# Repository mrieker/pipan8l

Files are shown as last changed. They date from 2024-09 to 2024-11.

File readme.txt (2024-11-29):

- - - - - - - - - - - - -

    Project has been absorbed into pdp8l project
    It is in folder pipan8l within the pdp8l project

- - - - - - - - - - - - -

RasPI-Zero-W uses /dev/i2c-1 to access the I2C bus going to the PCB.
Any RasPI that runs recent RasPI OS and has a 40-pin GPIO connector
should work, but I use a RasPI Zero because it is small, allowing me
to flip the processor over without any issue.

Here is a pic of everything running:

    https://www.outerworldapps.com/pdp8l-with-pipan8l.jpg

The PIPAN8L board is in the lower right corner plugged into the 8/L downside-up.
The PC screen on the left shows the pipan8l program on the lower terminal window,
with the ttpan8l program running on the upper terminal window.

- - - - - - - - - - - - -

The PCB plugs into slot 1 of the PDP-8/L in place of the console.

    RasPI-Zero-W ./pipan8l  ==>  PCB MCP23017s  ==>  PDP-8/L slot 1  ==>  rest of PDP-8/L

The RasPI can be powered from its own USB cable or from the PDP's 5V supply.
To power it from the PDP, install the jumper on the right end of the PCB.
I use the USB power so I can turn the PDP off and the RasPI will not need rebooting.

BE SURE TO USE 1.4mm THICK PCB STOCK.  1.6mm WON'T FIT.  The Digital spec says
board thickness of their modules is 0.056", which is a hair thicker than 1.4mm.
Even at 1.4mm, it takes a little gentle tapping to get it plugged in, so maybe
1.2mm might be better.  But even Digital's modules can be tough to insert.

- - - - - - - - - - - - -

./pipan8l runs the test program.  (You can type ./pip then press tab).
It reads commands from the prompt and can run scripts written in TCL.
The commands echo the switches and lights:

    setsw <switchname> <value>      - sets switch to a value
    getsw <switchname>              - gets value of a switch
    getreg <registername>           - gets value of a register (light bulbs)

And there is a command used to flush series of setsw commands:

    flushit                         - writes out any pending switch changes to MCP23017s
                                    - sets up to read MCP23017s when needed

There are a couple utility commands:

    ctrlcflag                       - sense if control-C has been pressed, optionallly clearing it
                                    - used for test scripts
                                    - otherwise, two control-Cs will abort out of pipan8l

    assemop <mnemonic> <operand>    - assemble the given assembly language instruction
    disasop <opcode>                - disassemble the given opcode to assemly language

And the pipan8lini.tcl script adds some higher-level commands:

    assem <address> <mnemonic> <operand>    - assemble the instruction and deposit in memory
    disas <start> <stop>                    - disassemble the instructions in given memory range
    dumpit                                  - print out all registers and switches
    flicksw <switchname>                    - flick the given switch on then off
    loadbin <filename>                      - load the given bin file into memory
    octal <value>                           - print the given value as 4-digit octal number
    rdmem <address>                         - read memory location
    startat <address>                       - does load address followed by start
    stepit                                  - do a single step then dump switches & lights
    wrmem <address> <value>                 - write the given value to memory

Note:
    The command processor is a TCL interpreter, so all numbers default to decimal.
    Prefix numbers with a 0 if you want to input an octal number.
    Use the octal command to convert number to octal for printing.

So when it's all running, you can do commands like:

    ./pipan8l               ;# start it running
    assem 0200 isz 030      ;# input a simple test program
    assem 0201 jmp 0200
    assem 0202 iac
    assem 0203 jmp 0200
    disas 0200 0203         ;# print it out to verify it
    startat 0200            ;# start it running
    flicksw stop            ;# stop it wherever it is
    setsw step 1            ;# turn on the step mode switch
    stepit                  ;# single cycle and print lights & switches
    stepit
    stepit                  ;# ... 3 times
    setsw step 0            ;# turn single cycle off
    flicksw cont            ;# continue
    dumpit                  ;# see it running
    dumpit
    flicksw stop            ;# stop processor so we can access memory
    octal [rdmem 030]       ;# read the counter and print in octal
    startat 0200            ;# restart program

Logged into RasPI:

$ sudo apt install tcl-dev
$ make
    ...
$ ./pipan8l

          ST=F  AC=0.7777 MA=0.7240 MB=7777 IR=7  OPR  SR=0000 DFLD IFLD MPRT STEP

TCL scripting, do 'help' for pipan8l-specific commands
  do 'exit' to exit pipan8l
pipan8l> assem 0200 isz 030
pipan8l> assem 0201 jmp 0200
pipan8l> assem 0202 iac
pipan8l> assem 0203 jmp 0200
pipan8l> disas 0200 0203
0200  2030  ISZ   0030
0201  5200  JMP   0200
0202  7001  IAC
0203  5200  JMP   0200
pipan8l> startat 0200
pipan8l> flicksw stop
pipan8l> setsw step 1
pipan8l> stepit
          ST=E  AC=0.0000 MA=0.0030 MB=0000 IR=2  ISZ  SR=0203 DFLD IFLD MPRT STEP
pipan8l> stepit
          ST=F  AC=0.0000 MA=0.5027 MB=5747 IR=2  ISZ  SR=0203 DFLD IFLD MPRT STEP
pipan8l> stepit
          ST=F  AC=0.0000 MA=0.0200 MB=2577 IR=5  JMP  SR=0203 DFLD IFLD MPRT STEP
pipan8l> setsw step 0
pipan8l> flicksw cont
pipan8l> dumpit
  RUN     ST=F  AC=0.0003 MA=0.4230 MB=5755 IR=3  DCA  SR=0203 DFLD IFLD MPRT
pipan8l> dumpit
  RUN     ST=E  AC=0.0005 MA=0.0100 MB=4177 IR=2  ISZ  SR=0203 DFLD IFLD MPRT
pipan8l> dumpit
  RUN     ST=F  AC=0.0006 MA=0.0233 MB=0560 IR=3  DCA  SR=0203 DFLD IFLD MPRT
pipan8l> flicksw stop
pipan8l> octal [rdmem 030]
4521
pipan8l> startat 0200
pipan8l>

- - - - - - - - - - - - -

It is somewhat tedious to keep entering dumpit commands to see what the panel is doing.
So there is a program called ttpan8l that will continuously dump the panel contents in
similar format to the actual PDP-8/L panel:

  PDP-8/L       -   - - -   - * -   - * *   - * -  0.0232  MA   IR [ - * *  DCA ]           1804 fps

                    * - -   * - *   * - *   - * -    4552  MB   ST [ f E d wc ca b ]

                -   - - -   - * *   - * -   - * -  0.0322  AC   ion per prt RUN

  MPRT  DFLD IFLD   - - -   - * -   - - -   - * *    0203  SR   ldad  start cont stop step exam  dep

Capital letters indicate the light is ON.
Small letters incdicate it is off.
Also, the ON lights are highlighted in green.

Leave pipan8l running in one terminal window of the RasPI.

Then, you can either run ttpan8l from another terminal window of the RasPI:

    ./ttpan8l

Or you can run it from a terminal window of a PC:

    ./ttpan8l <ip-address-of-raspi>

It does UDP to the pipan8l program to read the panel state as fast as it can.

- - - - - - - - - - - - -

There is a simple memory test script, testmem.tcl.
To use it:

    ./pipan8l testmem.tcl

    testzeroes 0 077            ;# test writing zeroes to memory 0000..0077
                                ;# writes then verifies

    testrands 0100 0177         ;# writes random numbers to 0100..0177 then verifies

    looptest testrands          ;# writes random numbers to 0000..0037 then verifies
                                ;#  then does 0040..0077 and verifies
                                ;#  then does 0100..0137 and verifies
                                ;#      ...
                                ;#  all the way through to 7740..7777
                                ;#  then repeats forever

Note:
    These tests run by simulating deposit and examine console operations so do not require that
    the processor be able to run a program.  It is just like someone manually doing load address,
    deposit and examines, flicking switches and reading lights, but it's all automated.

    The PDP-8/L circuitry limits the rate of panel operations (load address, examine, deposit, etc)
    to about 10 per second (for switch debouncing).  So these tests run S-L-O-W-L-Y.  But it beats
    doing it by hand!

$ ./pipan8l testmem.tcl

          ST=E  AC=0.1314 MA=0.0030 MB=0000 IR=2  ISZ  SR=0030 DFLD IFLD MPRT

  looptest - wrap one of the below test to run continuously
  testzeroes [beg [end]] - writes zeroes to all memory then verifies
  testones [beg [end]] - writes ones to all memory then verifies
  testrands [beg [end]] - writes randoms to all memory then verifies

TCL scripting, do 'help' for pipan8l-specific commands
  do 'exit' to exit pipan8l
pipan8l> looptest testrands

PASS 1

write randoms 0000..0037...
 0000
verify randoms...
 0000: 5476       0453       6021       3630       3042       7403       7603       7006      
 0010: 6343       2240       0554       5052       6070       4357       0443       1714      
 0020: 4525       2447       5673       5475       5153       7647       4334       4777      
 0030: 3427       5527       0065       0560       4074       4412       6431       2176      
write randoms 0040..0077...

verify randoms...
 0040: 6633       5621       7064       6502       4116       5460       6045       5404      
 0050: 2353       3512       1610       4655       7162       1455       0204       2604      
 0060: 6124       4103       6756       5633       3630       1045       0376       2535      
 0070: 6567       0310       5311       3551       4376       6131       6133       2620      
write randoms 0100..0137...
 0100
verify randoms...
 0100: 7356       6277       7265       5057       4612       2453       7610       5016      
 0110: 2501       1631       1034       3662       6530       6421       7232       5563      
 0120: 6133       7601       2607       0475       5310       1223       0230       0133      
 0130: 3302       1425       2162       0576       5154       3105       0162       0132      
write randoms 0140..0177...

verify randoms...
 0140: 6554       3664       2233       0117       0740       4636       3725       7377      
 0150: 7375       3102       3445       3022       6025       4306       6576       4673      
 0160: 2404       7613       1611       3307       2613       1267       3407       2102      
 0170: 1546       5553       2043       5753       4444       0007       6152       2125      
write randoms 0200..0237...

Here is example output with a broken memory:

verify randoms...
 0000: 7732       5502       0231!=1771 7464       3560       1064       5730       2377      
 0010: 7375       4246       1242!=1666 3224       4575       1537       3413       1176      
 0020: 7073       3573       0006!=1027 1612       0216       0744       2370       3205!=3204
 0030: 1007       5501       2044!=7144 7655       5171       6066       3023       2437      
 0040: 6355       4405       2353!=2757 6220       0563       6101       7601       6625      
 0050: 7147       3323       2014!=3614 3347       4360       5405       2725       0326      
 0060: 6773       6361!=2360 2757!=0714 7663       6745       6574       4167       0760      
 0070: 3444       2046       1104!=3104 2461       1606       7437       2360       4746      
 0100: 2425       0710       4006!=7327 0163       6610       7104       2370       3022      
 0110: 0246       1307       2014!=3515 3146       7261       0212       1023       5405      
 0120: 1526       1515       4102!=4123 3770       1405       0464       3416       2317!=2316
 0130: 0432       2531       5246!=5756 0713       4227       5537       0561       7164      
 0140: 0735       7736       0110!=3314 0066       5141       0377       6707       4753      
 0150: 6760       6203       1025!=3025 3551       5451       5634       7334       4476      
 0160: 7416       6567!=4567 7757!=7756 1442       7417       2605       1020       6734      
 0170: 3106       1414       0137!=0537 5142       2133       2045       3725       4332      
 0200: 3162       1570       0000!=0212 5752       3554       1153       4414       1204      
 0210: 3345       2605       0000!=3200 0417       5403       0227       1676       3160      
 0220: 5074       2470       0006!=6617 2367       3341       3555       5204       2455      
 0230: 1016       5226       2401!=2621 6533       3131       7554       1325       1741      
 0240: 6507       0162       0001!=2373 5762       1014       6243       7537       1353      
 0250: 7167       2177       0020!=0023 4406       7050       0275       0236       5150      
 0260: 7351       5001!=5000 4651!=4251 1177       1361       5122       6003       2647      
                                    ^ shorted diode                                        ^ bad inhibit driver resistor
                         ^ shorted diode

- - - - - - - - - - - - -

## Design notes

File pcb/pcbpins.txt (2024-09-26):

AA1 SW MPRT     A28
AB1 SW DFLD     A27
AC1 SW IFLD     B28
AD1 SW SR04     A26
AD2 SW SR03         A01
AE1 LT LINK     A25
AE2 SW SR02         A02
AF1 LT EMA      A24
AF2 SW SR01         A03
AH1 LT MB01     A23
AH2 SW SR00         A08
AJ1 LT MA01     A22
AJ2 LT AC00         A04
AK1 LT AC03     A21
AK2 LT MB00         A05
AL1 LT AC02     B27
AL2 LT AC01         A06
AM2 LT MA00     A07
AN2 LT MB02         B01
AP2 LT MA02         B02
AR2 LT MB03         B03
AS2 LT MA03     B26
AT2 LT MB04         B04
AU2 LT MA04     B25

BD2 LT AC04     B24
BE2 LT AC05         B05
BF2 LT MB05     B23
BH2 LT MA05         B06
BJ2 LT AC06     B22
BK2 LT AC07         B07
BL2 LT MB06     B21
BM2 LT MA06         C01
BP2 LT MA07         C02
BR2 LT MB07         C03
BS2 LT MB08     C27
BT2 LT MA08     C26
BU2 LT AC08     C25
BV2 LT AC09     C24

CD1 LT MB09     C22
CD2             C23
CE1 LT MA09     C21
CE2 SW SR09     C28
CF1 LT AC11     D27
CF2 SW SR10         B08
CH1 LT AC10     D26
CH2 SW SR08         C04
CJ1 LT MA10     D25
CJ2 SW SR07         C05
CK1 LT MB10     D24
CK2 SW SR06         C06
CL2 SW SR05         C08
CM1             D23
CM2 LT MB11         C07
CN2 LT MA11         D01
CP2 LT FET          D02
CR2 LT IR00         D03
CS2 LT ION          D04
CT2 LT PARE         D05
CU1             D22
CU2 LT EXE          D06
CV2 LT IR01         D21
CV2 LT IR01         D07

DB1             C21
DD2 LT IR02         E01
DE2 LT DEF      E27
DF2 LT PRTE         E02
DH1             E26
DH2 LT RUN          E03
DJ1             E25
DJ2 LT WCT          E04
DK2 LT CAD      E24
DL2 LT BRK          E05
DM2 SW SR11         E06
DN1 SW BNCY     E23
DN2 SW STOP     E22
DP2 SW CONT         E07
DR2 SW STRT     E21
DS2 SW LDAD         E08
DT2 SW STEP     E28
DU2 SW EXAM         D08
DV2 SW DEPO     D28

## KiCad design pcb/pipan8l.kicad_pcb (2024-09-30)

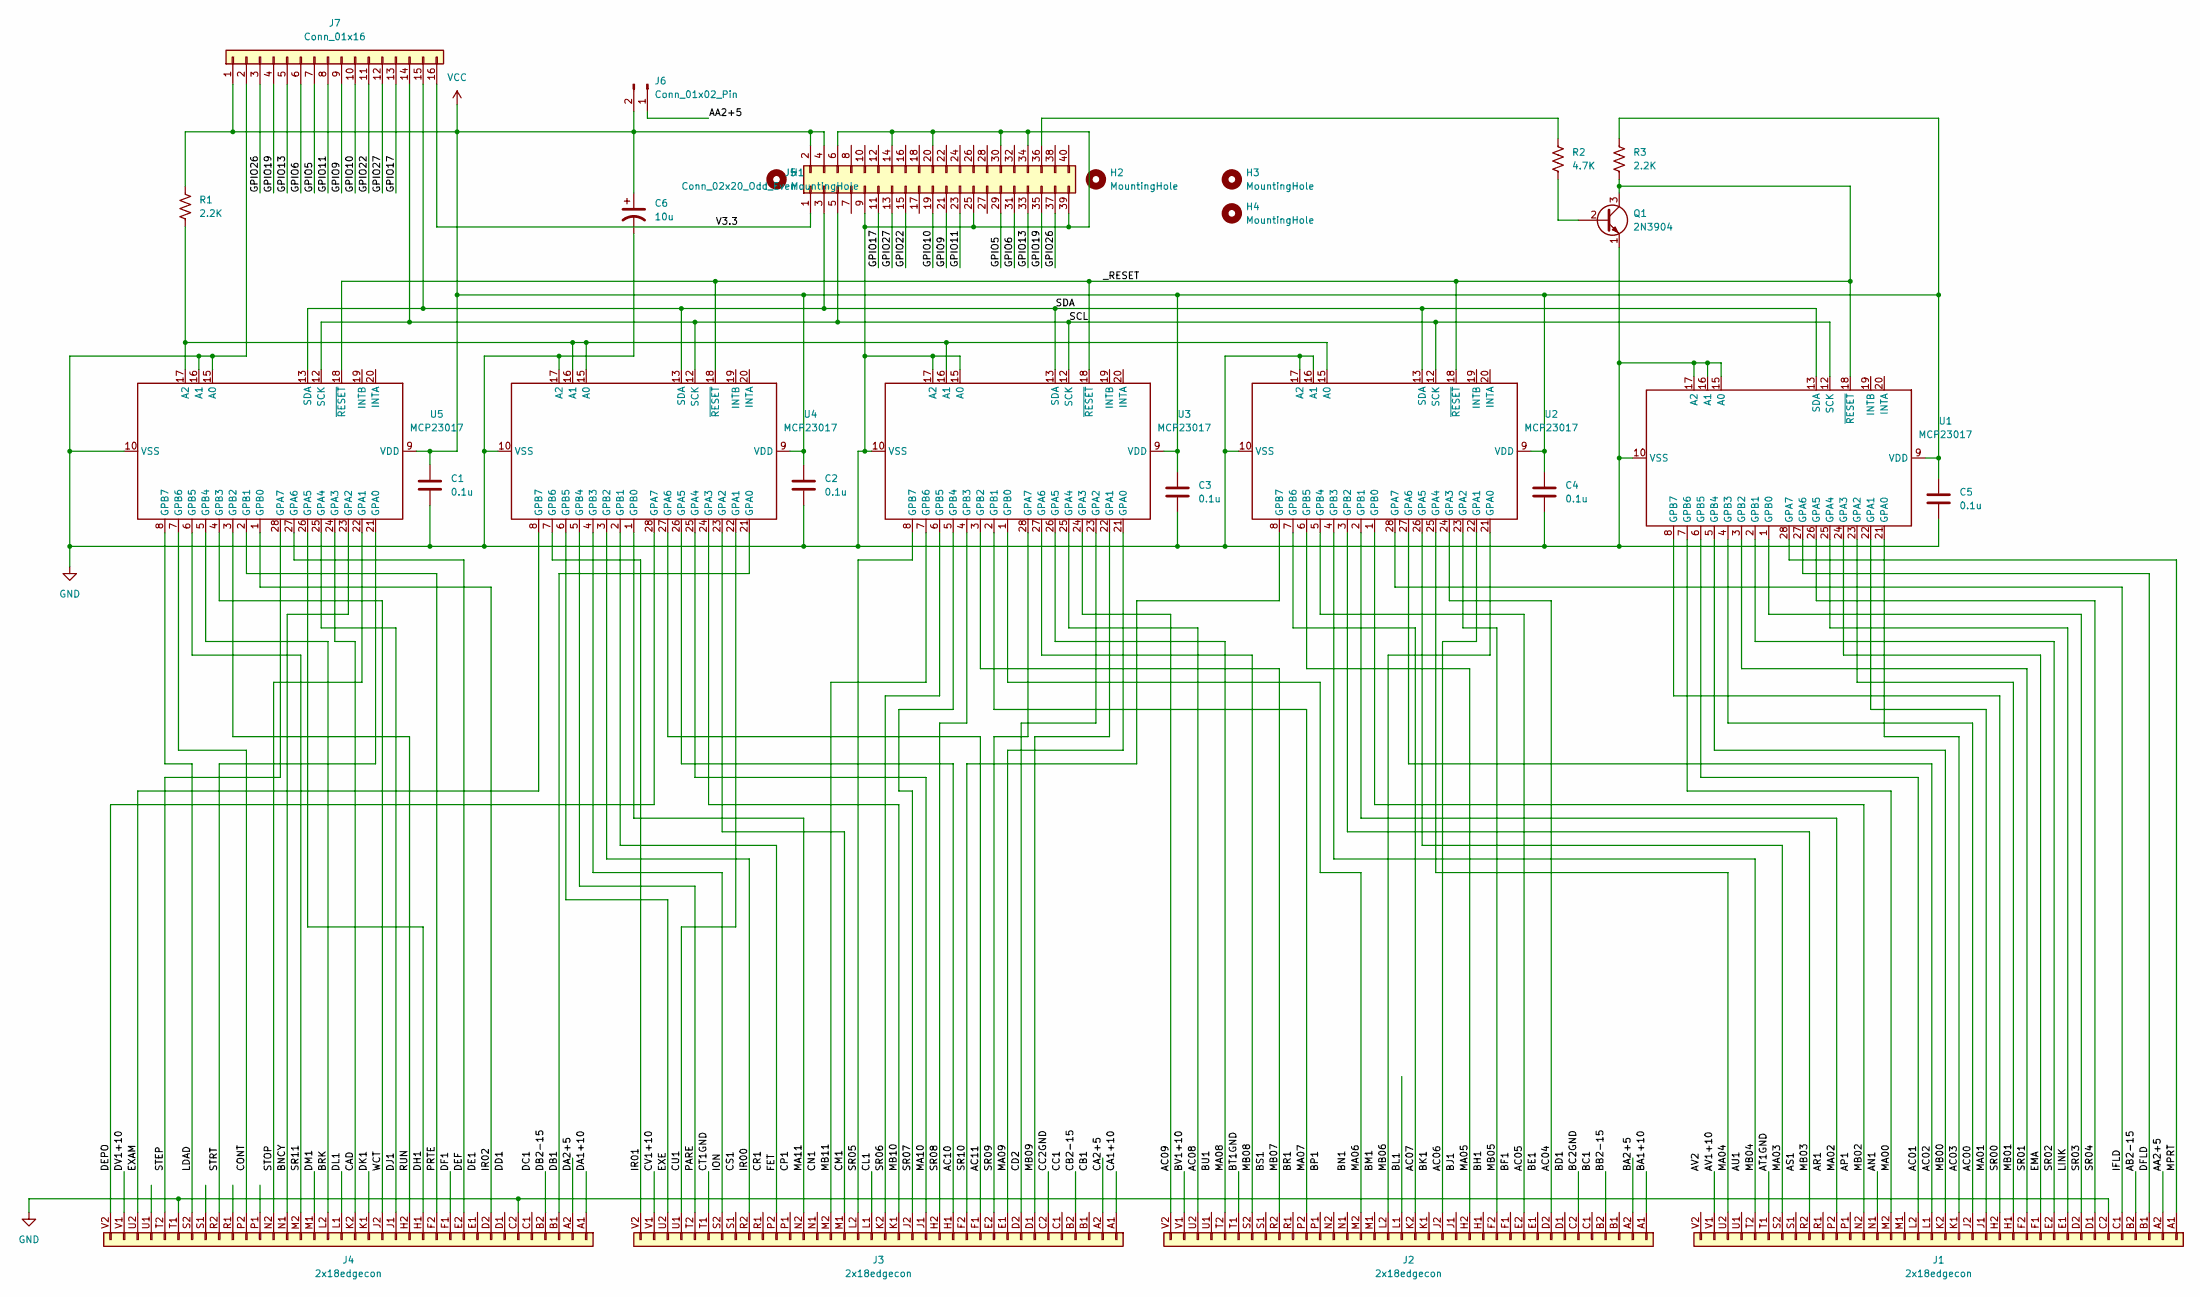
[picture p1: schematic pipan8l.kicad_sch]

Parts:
C1, C2, C3, C4, C5: 0.1u; C_Axial_L3.8mm_D2.6mm_P7.50mm_Horizontal
C6: 10u; CP_Axial_L11.0mm_D5.0mm_P18.00mm_Horizontal
H1, H2: MountingHole; MountingHole_3mm
H3, H4: MountingHole; MountingHole_8.4mm_M8
J1, J2, J3, J4: 2x18edgecon; 2x18-edge
J5: Conn_02x20_Odd_Even; PinHeader_2x20_P2.54mm_Vertical
J6: Conn_01x02_Pin; PinHeader_1x02_P2.54mm_Vertical
J7: Conn_01x16; PinHeader_1x16_P2.54mm_Horizontal
Q1: 2N3904; TO-92_Wide
R1, R3: 2.2K; R_Axial_DIN0207_L6.3mm_D2.5mm_P10.16mm_Horizontal
R2: 4.7K; R_Axial_DIN0207_L6.3mm_D2.5mm_P10.16mm_Horizontal
U1, U2, U3, U4, U5: MCP23017; DIP-28_W7.62mm_LongPads

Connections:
/AA2+5: J1.A2, J6.1
/AB2-15: J1.B2
/AC00: J1.J2, U1.4 (GPB3)
/AC01: J1.L2, U1.6 (GPB5)
/AC02: J1.L1, U2.27 (GPA6)
/AC03: J1.K1, U1.21 (GPA0)
/AC04: J2.D2, U2.24 (GPA3)
/AC05: J2.E2, U2.5 (GPB4)
/AC06: J2.J2, U2.22 (GPA1)
/AC07: J2.K2, U2.7 (GPB6)
/AC08: J2.U2, U3.25 (GPA4)
/AC09: J2.V2, U3.24 (GPA3)
/AC10: J3.H1, U4.26 (GPA5)
/AC11: J3.F1, U4.27 (GPA6)
/AN1: J1.N1
/AT1GND: J1.T1
/AV1+10: J1.V1
/BA1+10: J2.A1
/BA2+5: J2.A2
/BB2-15: J2.B2
/BC2GND: J2.C2
/BL1: J2.L1
/BNCY: J4.N1, U5.23 (GPA2)
/BRK: J4.L2, U5.5 (GPB4)
/BT1GND: J2.T1
/BV1+10: J2.V1
/CA1+10: J3.A1
/CA2+5: J3.A2
/CAD: J4.K2, U5.24 (GPA3)
/CB2-15: J3.B2
/CC2GND: J3.C2
/CD2: J3.D2, U3.23 (GPA2)
/CL1: J3.L1
/CM1: J3.M1, U4.23 (GPA2)
/CONT: J4.P2, U5.7 (GPB6)
/CT1GND: J3.T1
/CU1: J3.U1, U4.22 (GPA1)
/CV1+10: J3.V1
/DA1+10: J4.A1
/DA2+5: J4.A2
/DB1: J4.B1, U4.21 (GPA0)
/DB2-15: J4.B2
/DEF: J4.E2, U5.27 (GPA6)
/DEPO: J4.V2, U4.28 (GPA7)
/DF1: J4.F1
/DFLD: J1.B1, U1.27 (GPA6)
/DH1: J4.H1, U5.26 (GPA5)
/DJ1: J4.J1, U5.25 (GPA4)
/DK1: J4.K1
/DL1: J4.L1
/DM1: J4.M1
/DV1+10: J4.V1
/EMA: J1.F1, U1.24 (GPA3)
/EXAM: J4.U2, U4.8 (GPB7)
/EXE: J3.U2, U4.6 (GPB5)
/FET: J3.P2, U4.2 (GPB1)
/GPIO5: J5.29, J7.7
/GPIO6: J5.31, J7.6
/GPIO9: J5.21, J7.9
/GPIO10: J5.19, J7.10
/GPIO11: J5.23, J7.8
/GPIO13: J5.33, J7.5
/GPIO17: J5.11, J7.13
/GPIO19: J5.35, J7.4
/GPIO22: J5.15, J7.11
/GPIO26: J5.37, J7.3
/GPIO27: J5.13, J7.12
/IFLD: J1.C1, U2.28 (GPA7)
/ION: J3.S2, U4.4 (GPB3)
/IR00: J3.R2, U4.3 (GPB2)
/IR01: J3.V2, U4.7 (GPB6)
/IR02: J4.D2, U5.1 (GPB0)
/LDAD: J4.S2, U5.8 (GPB7)
/LINK: J1.E1, U1.25 (GPA4)
/MA00: J1.M2, U1.7 (GPB6)
/MA01: J1.J1, U1.22 (GPA1)
/MA02: J1.P2, U2.2 (GPB1)
/MA03: J1.S2, U2.26 (GPA5)
/MA04: J1.U2, U2.25 (GPA4)
/MA05: J2.H2, U2.6 (GPB5)
/MA06: J2.M2, U3.1 (GPB0)
/MA07: J2.P2, U3.2 (GPB1)
/MA08: J2.T2, U3.26 (GPA5)
/MA09: J3.E1, U3.21 (GPA0)
/MA10: J3.J1, U4.25 (GPA4)
/MA11: J3.N2, U4.1 (GPB0)
/MB00: J1.K2, U1.5 (GPB4)
/MB01: J1.H1, U1.23 (GPA2)
/MB02: J1.N2, U2.1 (GPB0)
/MB03: J1.R2, U2.3 (GPB2)
/MB04: J1.T2, U2.4 (GPB3)
/MB05: J2.F2, U2.23 (GPA2)
/MB06: J2.L2, U2.21 (GPA0)
/MB07: J2.R2, U3.3 (GPB2)
/MB08: J2.S2, U3.27 (GPA6)
/MB09: J3.D1, U3.22 (GPA1)
/MB10: J3.K1, U4.24 (GPA3)
/MB11: J3.M2, U3.7 (GPB6)
/MPRT: J1.A1, U1.28 (GPA7)
/PARE: J3.T2, U4.5 (GPB4)
/PRTE: J4.F2, U5.2 (GPB1)
/RUN: J4.H2, U5.3 (GPB2)
/SCL: J5.5, J7.14, U1.12 (SCK), U2.12 (SCK), U3.12 (SCK), U4.12 (SCK), U5.12 (SCK)
/SDA: J5.3, J7.15, U1.13 (SDA), U2.13 (SDA), U3.13 (SDA), U4.13 (SDA), U5.13 (SDA)
/SR00: J1.H2, U1.8 (GPB7)
/SR01: J1.F2, U1.3 (GPB2)
/SR02: J1.E2, U1.2 (GPB1)
/SR03: J1.D2, U1.1 (GPB0)
/SR04: J1.D1, U1.26 (GPA5)
/SR05: J3.L2, U3.8 (GPB7)
/SR06: J3.K2, U3.6 (GPB5)
/SR07: J3.J2, U3.5 (GPB4)
/SR08: J3.H2, U3.4 (GPB3)
/SR09: J3.E2, U3.28 (GPA7)
/SR10: J3.F2, U2.8 (GPB7)
/SR11: J4.M2, U5.6 (GPB5)
/STEP: J4.T2, U5.28 (GPA7)
/STOP: J4.N2, U5.22 (GPA1)
/STRT: J4.R2, U5.21 (GPA0)
/V3.3: J5.1, J7.16
/WCT: J4.J2, U5.4 (GPB3)
/_RESET: Q1.3 (C), R3.2, U1.18 (~RESET), U2.18 (~RESET), U3.18 (~RESET), U4.18 (~RESET), U5.18 (~RESET)
GND: C1.2, C2.2, C3.2, C4.2, C5.2, C6.2, J1.C2, J4.C2, J4.T1, J5.6, J5.9, J5.14, J5.20, J5.25, J5.30, J5.34, J5.39, J7.2, Q1.1 (E), U1.10 (VSS), U1.15 (A0), U1.16 (A1), U1.17 (A2), U2.10 (VSS), U2.16 (A1), U2.17 (A2), U3.10 (VSS), U3.15 (A0), U3.17 (A2), U4.10 (VSS), U4.17 (A2), U5.10 (VSS), U5.15 (A0), U5.16 (A1)
unnamed: J5.36, R2.1
unnamed: Q1.2 (B), R2.2
unnamed: R1.2, U2.15 (A0), U3.16 (A1), U4.15 (A0), U4.16 (A1), U5.17 (A2)
VCC: C1.1, C2.1, C3.1, C4.1, C5.1, C6.1, J5.2, J5.4, J6.2, J7.1, R1.1, R3.1, U1.9 (VDD), U2.9 (VDD), U3.9 (VDD), U4.9 (VDD), U5.9 (VDD)

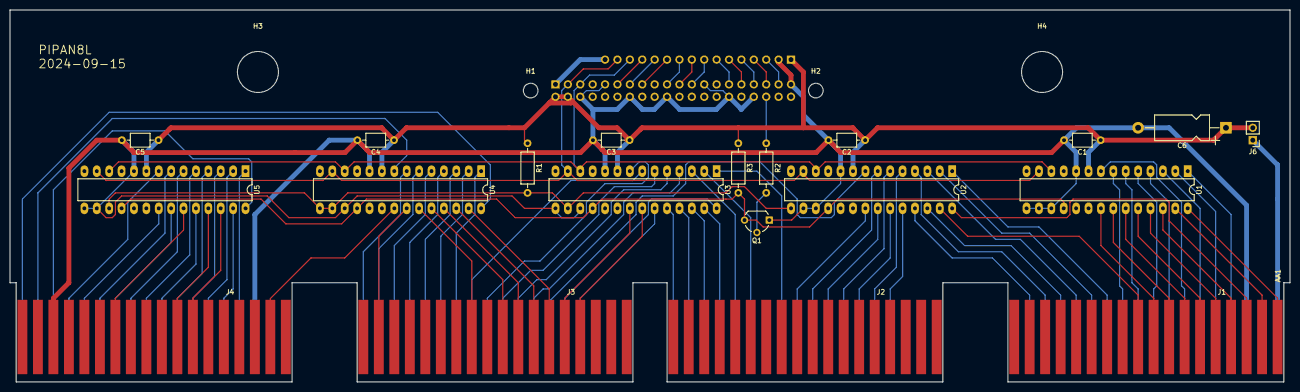
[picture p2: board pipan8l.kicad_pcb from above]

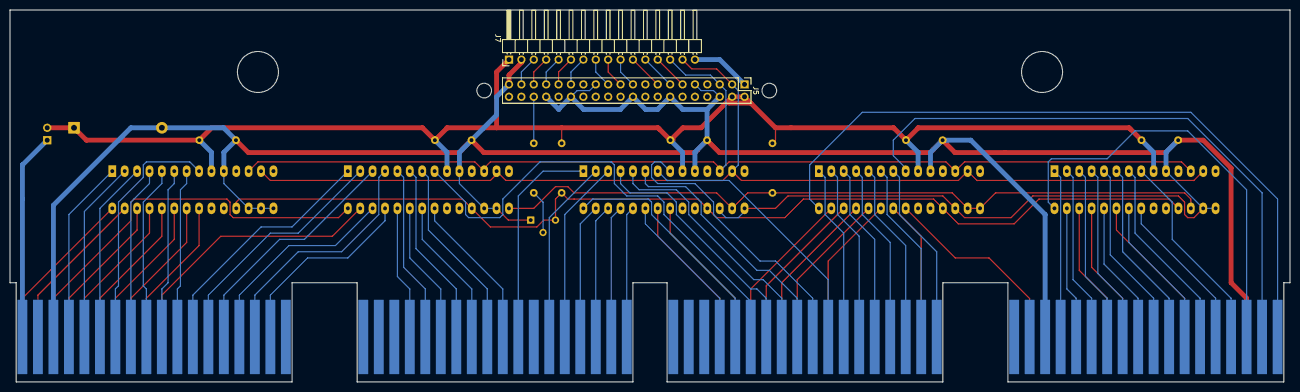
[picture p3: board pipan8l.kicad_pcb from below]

Board: 2 copper layers, 262.3 x 76.2 mm, 26 parts (2 on the bottom side), 101 nets.

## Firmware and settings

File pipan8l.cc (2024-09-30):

//    Copyright (C) Mike Rieker, Beverly, MA USA
//    www.outerworldapps.com
//
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
//    EXPECT it to FAIL when someone's HeALTh or PROpeRTy is at RISk.
//
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
//    http://www.gnu.org/licenses/gpl-2.0.html

// run via pipan8l shell script:
//  ./pipan8l [-sim] [<scriptfile.tcl>]

#include <fcntl.h>
#include <netinet/in.h>
#include <pthread.h>
#include <signal.h>
#include <stdint.h>
#include <stdio.h>
#include <stdlib.h>
#include <string.h>
#include <sys/socket.h>
#include <sys/time.h>
#include <tcl.h>
#include <unistd.h>

#include "assemble.h"
#include "disassemble.h"
#include "padlib.h"
#include "pindefs.h"
#include "readprompt.h"
#include "udppkt.h"

#define ABORT() do { fprintf (stderr, "abort() %s:%d\n", __FILE__, __LINE__); abort (); } while (0)
#define ASSERT(cond) do { if (__builtin_constant_p (cond)) { if (!(cond)) asm volatile ("assert failure line %c0" :: "i"(__LINE__)); } else { if (!(cond)) ABORT (); } } while (0)

struct FunDef {
    Tcl_ObjCmdProc *func;
    char const *name;
    char const *help;
};

struct PermSw {
    char const *name;
    int nbits;
    int pinums[12];
};

struct RegBit {
    char const *name;
    int pinum;
};

// internal TCL commands
static Tcl_ObjCmdProc cmd_assemop;
static Tcl_ObjCmdProc cmd_ctrlcflag;
static Tcl_ObjCmdProc cmd_disasop;
static Tcl_ObjCmdProc cmd_flushit;
static Tcl_ObjCmdProc cmd_getpin;
static Tcl_ObjCmdProc cmd_getreg;
static Tcl_ObjCmdProc cmd_getsw;
static Tcl_ObjCmdProc cmd_help;
static Tcl_ObjCmdProc cmd_setpin;
static Tcl_ObjCmdProc cmd_setsw;

static FunDef const fundefs[] = {
    { cmd_assemop,    "assemop",    "assemble instruction" },
    { cmd_ctrlcflag,  "ctrlcflag",  "read and clear control-C flag" },
    { cmd_disasop,    "disasop",    "disassemble instruction" },
    { cmd_flushit,    "flushit",    "flush writes / invalidate reads" },
    { cmd_getpin,     "getpin",     "get gpio pin" },
    { cmd_getreg,     "getreg",     "get register value" },
    { cmd_getsw,      "getsw",      "get switch value" },
    { cmd_help,       "help",       "print this help" },
    { cmd_setpin,     "setpin",     "set gpio pin" },
    { cmd_setsw,      "setsw",      "set switch value" },
    { NULL, NULL, NULL }
};

static int const acbits[] = { P_AC00, P_AC01, P_AC02, P_AC03, P_AC04, P_AC05, P_AC06, P_AC07, P_AC08, P_AC09, P_AC10, P_AC11, -1 };
static int const irbits[] = { P_IR00, P_IR01, P_IR02, -1 };
static int const mabits[] = { P_MA00, P_MA01, P_MA02, P_MA03, P_MA04, P_MA05, P_MA06, P_MA07, P_MA08, P_MA09, P_MA10, P_MA11, -1 };
static int const mbbits[] = { P_MB00, P_MB01, P_MB02, P_MB03, P_MB04, P_MB05, P_MB06, P_MB07, P_MB08, P_MB09, P_MB10, P_MB11, -1 };
static int const srbits[] = { P_SR00, P_SR01, P_SR02, P_SR03, P_SR04, P_SR05, P_SR06, P_SR07, P_SR08, P_SR09, P_SR10, P_SR11, -1 };

static PermSw const permsws[] = {
    { "bncy",  1, P_BNCY },
    { "cont",  1, P_CONT },
    { "dep",   1, P_DEP  },
    { "dfld",  1, P_DFLD },
    { "exam",  1, P_EXAM },
    { "ifld",  1, P_IFLD },
    { "ldad",  1, P_LDAD },
    { "mprt",  1, P_MPRT },
    { "sr", 12, P_SR11, P_SR10, P_SR09, P_SR08, P_SR07, P_SR06, P_SR05, P_SR04, P_SR03, P_SR02, P_SR01, P_SR00 },
    { "start", 1, P_STRT },
    { "step",  1, P_STEP },
    { "stop",  1, P_STOP },
    {  NULL,   0, 0 }
};

static uint16_t const wrmsks[P_NU16S] = { P0_WMSK, P1_WMSK, P2_WMSK, P3_WMSK, P4_WMSK };

static bool volatile ctrlcflag;
static bool rdpadsvalid;
static bool wrpadsdirty;
static char *inihelp;
static int logfd, pipefds[2], oldstdoutfd;
static PadLib *padlib;
static pthread_mutex_t padmutex = PTHREAD_MUTEX_INITIALIZER;
static pthread_t logtid;
static sigset_t sigintmask;
static uint16_t rdpads[P_NU16S];
static uint16_t wrpads[P_NU16S];

static void siginthand (int signum);
static void *logthread (void *dummy);
static void closelog ();
static int writepipe (int fd, char const *buf, int len);
static void Tcl_SetResultF (Tcl_Interp *interp, char const *fmt, ...);
static uint16_t getreg (int const *pins);
static void setpin (int pin, bool set);
static bool getpin (int pin);
static void flushit ();
static void *udpthread (void *dummy);




int main (int argc, char **argv)
{
    setlinebuf (stdout);
    sigemptyset (&sigintmask);
    sigaddset (&sigintmask, SIGINT);

    bool simit = false;
    char const *fn = NULL;
    char const *logname = NULL;
    for (int i = 0; ++ i < argc;) {
        if (strcasecmp (argv[i], "-log") == 0) {
            if ((++ i >= argc) || (argv[i][0] == '-')) {
                fprintf (stderr, "missing filename after -log\n");
                return 1;
            }
            logname = argv[i];
            continue;
        }
        if (strcasecmp (argv[i], "-sim") == 0) {
            simit = true;
            continue;
        }
        if ((argv[i][0] == '-') || (fn != NULL)) {
            fprintf (stderr, "usage: %s [-log <logfilename>] [-simit] [<tclfilename>]\n", argv[0]);
            return 1;
        }
        fn = argv[i];
    }

    padlib = simit ? (PadLib *) new SimLib () : (PadLib *) new I2CLib ();
    padlib->openpads ();
    // initialize switches from existing switch states
    padlib->readpads (rdpads);
    for (int i = 0; i < P_NU16S; i ++) wrpads[i] = rdpads[i];

    Tcl_FindExecutable (argv[0]);

    Tcl_Interp *interp = Tcl_CreateInterp ();
    if (interp == NULL) ABORT ();
    int rc = Tcl_Init (interp);
    if (rc != TCL_OK) {
        char const *err = Tcl_GetStringResult (interp);
        if ((err != NULL) && (err[0] != 0)) {
            fprintf (stderr, "pipan8l: error %d initialing tcl: %s\n", rc, err);
        } else {
            fprintf (stderr, "pipan8l: error %d initialing tcl\n", rc);
        }
        ABORT ();
    }

    // https://www.tcl-lang.org/man/tcl/TclLib/CrtObjCmd.htm

    for (int i = 0; fundefs[i].name != NULL; i ++) {
        if (Tcl_CreateObjCommand (interp, fundefs[i].name, fundefs[i].func, NULL, NULL) == NULL) ABORT ();
    }

    // redirect stdout if -log given
    if (logname != NULL) {
        fflush (stdout);
        fflush (stderr);

        // open log file
        logfd = open (logname, O_WRONLY | O_CREAT | O_APPEND, 0666);
        if (logfd < 0) {
            fprintf (stderr, "error creating %s: %m\n", logname);
            return 1;
        }

        // save old stdout so we can fclose stdout then fclose it
        oldstdoutfd = dup (STDOUT_FILENO);
        if (oldstdoutfd < 0) ABORT ();

        // create pipe that will be used for new stdout then open stdout on it
        if (pipe (pipefds) < 0) ABORT ();
        fclose (stdout);  // fclose() after pipe() so pipefds[0] doesn't get STDOUT_FILENO
        if (dup2 (pipefds[1], STDOUT_FILENO) < 0) ABORT ();
        close (pipefds[1]);
        pipefds[1] = -1;
        stdout = fdopen (STDOUT_FILENO, "w");
        if (stdout == NULL) ABORT ();
        setlinebuf (stdout);

        // logfd = log file
        // stdout = write end of pipe
        // oldstdout = original stdout (probably a tty)
        // pipefds[0] = read end of pipe

        // create thread to copy from pipe to both old stdout and log file
        if (pthread_create (&logtid, NULL, logthread, NULL) < 0) ABORT ();
        pthread_detach (logtid);
        atexit (closelog);

        // \377 means only write to log file, not to old stdout
        printf ("\377*S*T*A*R*T*U*P*\n");
    }

    // create udp server thread
    {
        pthread_t udptid;
        int rc = pthread_create (&udptid, NULL, udpthread, NULL);
        if (rc != 0) ABORT ();
    }

    // set ctrlcflag on control-C, but exit if two in a row
    signal (SIGINT, siginthand);

    // maybe there is a script init file
    char const *scriptini = getenv ("pipan8lini");
    if (scriptini != NULL) {
        rc = Tcl_EvalFile (interp, scriptini);
        if (rc != TCL_OK) {
            char const *err = Tcl_GetStringResult (interp);
            if ((err == NULL) || (err[0] == 0)) fprintf (stderr, "pipan8l: error %d evaluating scriptini %s\n", rc, scriptini);
                                  else fprintf (stderr, "pipan8l: error %d evaluating scriptini %s: %s\n", rc, scriptini, err);
            Tcl_EvalEx (interp, "puts $::errorInfo", -1, TCL_EVAL_GLOBAL);
            return 1;
        }
        char const *res = Tcl_GetStringResult (interp);
        if ((res != NULL) && (res[0] != 0)) inihelp = strdup (res);
    }

    // if given a filename, process that file as a whole
    if (fn != NULL) {
        rc = Tcl_EvalFile (interp, fn);
        if (rc != TCL_OK) {
            char const *res = Tcl_GetStringResult (interp);
            if ((res == NULL) || (res[0] == 0)) fprintf (stderr, "pipan8l: error %d evaluating script %s\n", rc, fn);
                                  else fprintf (stderr, "pipan8l: error %d evaluating script %s: %s\n", rc, fn, res);
            Tcl_EvalEx (interp, "puts $::errorInfo", -1, TCL_EVAL_GLOBAL);
            return 1;
        }
    }

    // either way, prompt and process commands from stdin
    // to have a script file with no stdin processing, end script file with 'exit'
    puts ("\nTCL scripting, do 'help' for pipan8l-specific commands");
    puts ("  do 'exit' to exit pipan8l");
    for (char const *line;;) {
        ctrlcflag = false;
        line = readprompt ("pipan8l> ");
        ctrlcflag = false;
        if (line == NULL) break;
        rc = Tcl_EvalEx (interp, line, -1, TCL_EVAL_GLOBAL);
        char const *res = Tcl_GetStringResult (interp);
        if (rc != TCL_OK) {
            if ((res == NULL) || (res[0] == 0)) fprintf (stderr, "pipan8l: error %d evaluating command\n", rc);
                                  else fprintf (stderr, "pipan8l: error %d evaluating command: %s\n", rc, res);
            Tcl_EvalEx (interp, "puts $::errorInfo", -1, TCL_EVAL_GLOBAL);
        }
        else if ((res != NULL) && (res[0] != 0)) puts (res);
    }

    Tcl_Finalize ();

    return 0;
}

static void siginthand (int signum)
{
    if ((isatty (STDIN_FILENO) > 0) && (write (STDIN_FILENO, "\n", 1) > 0)) { }
    if (logfd > 0) writepipe (STDOUT_FILENO, "\377^C\n", 4);
    if (ctrlcflag) exit (1);
    ctrlcflag = true;
}

// read from pipefds[0] and write to both logfd and oldstdoutfd
// need this instead of 'tee' command cuz control-C aborts 'tee'
static void *logthread (void *dummy)
{
    bool atbol = true;
    bool echoit = true;
    char buff[4096];
    int rc;
    while ((rc = read (pipefds[0], buff, sizeof buff)) > 0) {
        struct timeval nowtv;
        if (gettimeofday (&nowtv, NULL) < 0) ABORT ();
        struct tm nowtm = *localtime (&nowtv.tv_sec);

        int ofs = 0;
        int len;
        while ((len = rc - ofs) > 0) {

            // \377 means write following line only to log file, don't echo to old stdout
            char *p = (char *) memchr (buff + ofs, '\377', len);
            if (p != NULL) len = p - buff - ofs;
            if (len == 0) {
                echoit = false;
                ofs ++;
                continue;
            }

            // chop amount being written to one line so we can prefix next line with timestamp
            char *q = (char *) memchr (buff + ofs, '\n', len);
            if (q != NULL) len = ++ q - buff - ofs;

            // maybe echo to old stdout
            if (echoit && (writepipe (oldstdoutfd, buff + ofs, len) < 0)) {
                fprintf (stderr, "logthread: error writing to stdout: %m\n");
                ABORT ();
            }

            // always wtite to log file with timestamp
            if (atbol) dprintf (logfd, "%02d:%02d:%02d.%06d ", nowtm.tm_hour, nowtm.tm_min, nowtm.tm_sec, (int) nowtv.tv_usec);
            if (writepipe (logfd, buff + ofs, len) < 0) {
                fprintf (stderr, "logthread: error writing to logfile: %m\n");
                ABORT ();
            }

            // if just reached eol, re-enable stdout echoing and remember to timestamp next line
            ofs    += len;
            atbol   = (buff[ofs-1] == '\n');
            echoit |= atbol;
        }
    }
    close (logfd);
    return NULL;
}

// make sure log file gets last bit written to stdout
static void closelog ()
{
    fclose (stdout);
    stdout = NULL;
    pthread_join (logtid, NULL);
    logtid = 0;
}

static int writepipe (int fd, char const *buf, int len)
{
    while (len > 0) {
        int rc = write (fd, buf, len);
        if (len <= 0) {
            if (len == 0) errno = EPIPE;
            return -1;
        }
        buf += rc;
        len -= rc;
    }
    return 0;
}




// assemble instruciton
//  assemop [address] opcode
static int cmd_assemop (ClientData clientdata, Tcl_Interp *interp, int objc, Tcl_Obj *const objv[])
{
    if (objc > 1) {
        int i = 1;
        char const *stri = Tcl_GetString (objv[i]);
        if (strcasecmp (stri, "help") == 0) {
            puts ("");
            puts ("  assemop [<address>] <opcode>...");
            puts ("   address = integer address of the opcode (for page-relative addresses)");
            puts ("    opcode = opcode string(s)");
            puts ("");
            return TCL_OK;
        }

        char *p;
        uint16_t address = strtoul (stri, &p, 0);
        if ((objc == 2) || (p == stri) || (*p != 0)) address = 0200;
                              else stri = Tcl_GetString (objv[++i]);

        std::string opstr;
        while (true) {
            opstr.append (stri);
            if (++ i >= objc) break;
            opstr.push_back (' ');
            stri = Tcl_GetString (objv[i]);
        }

        uint16_t opcode;
        char *err = assemble (opstr.c_str (), address, &opcode);
        if (err != NULL) {
            Tcl_SetResult (interp, err, (void (*) (char *)) free);
            return TCL_ERROR;
        }
        Tcl_SetObjResult (interp, Tcl_NewIntObj (opcode));
        return TCL_OK;
    }

    Tcl_SetResult (interp, (char *) "bad number of arguments", TCL_STATIC);
    return TCL_ERROR;
}

// read and clear the control-C flag
static int cmd_ctrlcflag (ClientData clientdata, Tcl_Interp *interp, int objc, Tcl_Obj *const objv[])
{
    bool oldctrlcflag = ctrlcflag;
    switch (objc) {
        case 2: {
            char const *opstr = Tcl_GetString (objv[1]);
            if (strcasecmp (opstr, "help") == 0) {
                puts ("");
                puts ("  ctrlcflag - read control-C flag");
                puts ("  ctrlcflag <boolean> - read control-C flag and set to given value");
                puts ("");
                puts ("  in any case, control-C flag is cleared at command prompt");
                puts ("");
                return TCL_OK;
            }
            int temp;
            int rc = Tcl_GetBooleanFromObj (interp, objv[1], &temp);
            if (rc != TCL_OK) return rc;
            if (sigprocmask (SIG_BLOCK, &sigintmask, NULL) != 0) ABORT ();
            oldctrlcflag = ctrlcflag;
            ctrlcflag = temp != 0;
            if (sigprocmask (SIG_UNBLOCK, &sigintmask, NULL) != 0) ABORT ();
            // fallthrough
        }
        case 1: {
            Tcl_SetObjResult (interp, Tcl_NewIntObj (oldctrlcflag));
            return TCL_OK;
        }
    }
    Tcl_SetResult (interp, (char *) "bad number of arguments", TCL_STATIC);
    return TCL_ERROR;
}

// disassemble instruciton
//  disasop opcode [address]
static int cmd_disasop (ClientData clientdata, Tcl_Interp *interp, int objc, Tcl_Obj *const objv[])
{
    int opcode = -1;
    int addr = 0200;

    switch (objc) {
        case 2: {
            char const *opstr = Tcl_GetString (objv[1]);
            if (strcasecmp (opstr, "help") == 0) {
                puts ("");
                puts ("  disasop <opcode> [<address>]");
                puts ("    opcode = integer opcode");
                puts ("   address = integer address of the opcode (for page-relative addresses)");
                puts ("");
                return TCL_OK;
            }
            int rc = Tcl_GetIntFromObj (interp, objv[1], &opcode);
            if (rc != TCL_OK) return rc;
            break;
        }
        case 3: {
            int rc = Tcl_GetIntFromObj (interp, objv[1], &opcode);
            if (rc == TCL_OK) rc = Tcl_GetIntFromObj (interp, objv[2], &addr);
            if (rc != TCL_OK) return rc;
            break;
        }
        default: {
            Tcl_SetResult (interp, (char *) "bad number of arguments", TCL_STATIC);
            return TCL_ERROR;
        }
    }

    std::string str = disassemble (opcode, addr);
    Tcl_SetResult (interp, strdup (str.c_str ()), (void (*) (char *)) free);
    return TCL_OK;
}

static int cmd_flushit (ClientData clientdata, Tcl_Interp *interp, int objc, Tcl_Obj *const objv[])
{
    switch (objc) {
        case 1: {
            if (pthread_mutex_lock (&padmutex) != 0) ABORT ();
            flushit ();
            rdpadsvalid = false;
            if (pthread_mutex_unlock (&padmutex) != 0) ABORT ();
            return TCL_OK;
        }
        case 2: {
            char const *swname = Tcl_GetString (objv[1]);
            if (strcasecmp (swname, "help") == 0) {
                puts ("");
                puts (" flushit");
                puts ("   flush pending writes to paddles");
                puts ("   invalidate cached paddle reads");
                puts ("");
                return TCL_OK;
            }
            break;
        }
    }
    Tcl_SetResult (interp, (char *) "bad number of arguments", TCL_STATIC);
    return TCL_ERROR;
}

// get gpio pin
static int cmd_getpin (ClientData clientdata, Tcl_Interp *interp, int objc, Tcl_Obj *const objv[])
{
    switch (objc) {
        case 2: {
            char const *regname = Tcl_GetString (objv[1]);
            if (strcasecmp (regname, "help") == 0) {
                puts ("");
                puts (" getpin <pinnumber>");
                puts ("   0.. 7 : U1 GPA0..7");
                puts ("   8..15 : U1 GPB0..7");
                puts ("  16..23 : U2 GPA0..7");
                puts ("  24..31 : U2 GPB0..7");
                puts ("  32..39 : U3 GPA0..7");
                puts ("  40..47 : U3 GPB0..7");
                puts ("  48..55 : U4 GPA0..7");
                puts ("  56..63 : U4 GPB0..7");
                puts ("  64..71 : U5 GPA0..7");
                puts ("  72..79 : U5 GPB0..7");
                puts ("");
                return TCL_OK;
            }
            int pinnum;
            int rc = Tcl_GetIntFromObj (interp, objv[1], &pinnum);
            if (rc != TCL_OK) return rc;
            if ((pinnum < 0) || (pinnum > 79)) {
                Tcl_SetResultF (interp, "bad pin number %d\n", pinnum);
                return TCL_ERROR;
            }
            int pinval = padlib->readpin (pinnum);
            if (pinval < 0) {
                Tcl_SetResultF (interp, "error reading pin %d\n", pinnum);
                return TCL_ERROR;
            }
            Tcl_SetObjResult (interp, Tcl_NewIntObj (pinval));
            return TCL_OK;
        }
    }
    Tcl_SetResult (interp, (char *) "bad number of arguments", TCL_STATIC);
    return TCL_ERROR;
}
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

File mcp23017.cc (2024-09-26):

//    Copyright (C) Mike Rieker, Beverly, MA USA
//    www.outerworldapps.com
//
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
//    EXPECT it to FAIL when someone's HeALTh or PROpeRTy is at RISk.
//
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
//    http://www.gnu.org/licenses/gpl-2.0.html

// Test MCP23017

//  ./mcp23017 /dev/i2c-1 <chipnumber>
//  top 4 bits of both ports are outputs
//  bottom 4 bits of both ports are inputs

/*
  assuming single mcp23017 plugged into address 4:
    $ i2cdetect -y 1
         0  1  2  3  4  5  6  7  8  9  a  b  c  d  e  f
    00:                         -- -- -- -- -- -- -- -- 
    10: -- -- -- -- -- -- -- -- -- -- -- -- -- -- -- -- 
    20: -- -- -- -- 24 -- -- -- -- -- -- -- -- -- -- -- 
    30: -- -- -- -- -- -- -- -- -- -- -- -- -- -- -- -- 
    40: -- -- -- -- -- -- -- -- -- -- -- -- -- -- -- -- 
    50: -- -- -- -- -- -- -- -- -- -- -- -- -- -- -- -- 
    60: -- -- -- -- -- -- -- -- -- -- -- -- -- -- -- -- 
    70: -- -- -- -- -- -- -- --                         
    $
*/

#include <fcntl.h>
#include <linux/i2c.h>
#include <linux/i2c-dev.h>
#include <stdint.h>
#include <stdio.h>
#include <stdlib.h>
#include <string.h>
#include <sys/ioctl.h>
#include <unistd.h>

#define I2CBA  0x20     // I2C address of MCP23017 chip 0

#define IODIRA   0x00   // pin direction: '1'=input ; '0'=output
#define IODIRB   0x01   //   IO<7> must be set to 'output'
#define IPOLA    0x02   // input polarity: '1'=flip ; '0'=normal
#define IPOLB    0x03
#define GPINTENA 0x04   // interrupt on difference bitmask
#define GPINTENB 0x05
#define DEFVALA  0x06   // comparison value for interrupt on difference
#define DEFVALB  0x07
#define INTCONA  0x08   // more interrupt comparison
#define INTCONB  0x09
#define IOCONA   0x0A   // various control bits
#define IOCONB   0x0B
#define GPPUA    0x0C   // pullup enable bits
#define GPPUB    0x0D   //   '0' = disabled ; '1' = enabled
#define INTFA    0x0E   // interrupt flag bits
#define INTFB    0x0F
#define INTCAPA  0x10   // interrupt captured value
#define INTCAPB  0x11
#define GPIOA    0x12   // reads pin state
#define GPIOB    0x13
#define OLATA    0x14   // output pin latch
#define OLATB    0x15

static int i2cfd;

uint16_t read16 (uint8_t addr, uint8_t reg);
void write16 (uint8_t addr, uint8_t reg, uint16_t word);

int main (int argc, char **argv)
{
    if (argc != 3) {
        fprintf (stderr, "usage: ./mcp23017 /dev/i2c-1 n\n");
        return -1;
    }

    i2cfd = open (argv[1], O_RDWR);
    if (i2cfd < 0) {
        fprintf (stderr, "main: error opening %s: %m\n", argv[1]);
        abort ();
    }

    int chipno = atoi (argv[2]);

    write16 (I2CBA + chipno, IODIRA, 0x0F0F);

    while (true) {
        uint16_t word = read16 (I2CBA + chipno, GPIOA);
        printf ("%d  %04X  =>  ", chipno, word);
        char inbuf[30];
        if (fgets (inbuf, sizeof inbuf, stdin) == NULL) break;
        word = strtoul (inbuf, NULL, 16);
        write16 (I2CBA + chipno, OLATA, word);
    }
}

// read 16-bit value from MCP23017 on I2C bus
//  input:
//   addr = MCP23017 address
//   reg = starting register within MCP23017
//  output:
//   returns [07:00] = reg+0 contents
//           [15:08] = reg+1 contents
uint16_t read16 (uint8_t addr, uint8_t reg)
{
    struct i2c_rdwr_ioctl_data msgset;
    struct i2c_msg iomsgs[2];
    uint8_t wbuf[1], rbuf[2];

    memset (&msgset, 0, sizeof msgset);
    memset (iomsgs, 0, sizeof iomsgs);

    wbuf[0] = reg;              // MCP23017 register number
    iomsgs[0].addr  = addr;
    iomsgs[0].flags = 0;        // write
    iomsgs[0].buf   = wbuf;
    iomsgs[0].len   = 1;

    iomsgs[1].addr  = addr;
    iomsgs[1].flags = I2C_M_RD; // read
    iomsgs[1].buf   = rbuf;
    iomsgs[1].len   = 2;

    msgset.msgs = iomsgs;
    msgset.nmsgs = 2;

    int rc = ioctl (i2cfd, I2C_RDWR, &msgset);
    if (rc < 0) {
        fprintf (stderr, "read16: error reading from %02X.%02X: %m\n", addr, reg);
        abort ();
    }

    // reg+1 in upper byte; reg+0 in lower byte
    return (rbuf[1] << 8) | rbuf[0];
}

// write 16-bit value to MCP23017 registers on I2C bus
//  input:
//   addr = MCP23017 address
//   reg = starting register within MCP23017
//   word = value to write
//          word[07:00] => reg+0
//          word[15:08] => reg+1
void write16 (uint8_t addr, uint8_t reg, uint16_t word)
{
    struct i2c_rdwr_ioctl_data msgset;
    struct i2c_msg iomsgs[1];
    uint8_t buf[3];

    memset (&msgset, 0, sizeof msgset);
    memset (iomsgs, 0, sizeof iomsgs);

    buf[0] = reg;               // MCP23017 register number
    buf[1] = word;              // byte for reg+0
    buf[2] = word >> 8;         // byte for reg+1

    iomsgs[0].addr  = addr;
    iomsgs[0].flags = 0;        // write
    iomsgs[0].buf   = buf;
    iomsgs[0].len   = 3;

    msgset.msgs  = iomsgs;
    msgset.nmsgs = 1;

    int rc = ioctl (i2cfd, I2C_RDWR, &msgset);
    if (rc < 0) {
        fprintf (stderr, "write16: error writing to %02X.%02X: %m\n", addr, reg);
        abort ();
    }
}

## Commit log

2024-09-26 initial files for I2C-based console using a RasPI-Zero-W
    also can connect the RasPI-Zero-W to a ZTurn for testing
    uses the enclosed pdp8v/zynq vivado project for zync code
    [pipanel.kicad_pcb, pipanel.kicad_sch]
2024-09-26 remove debug prints from i2clib.cc
2024-09-26 have PDP-8/V Zynq frontpanel.v exam switch not increment unless used twice in a row
    ...so it's more like PDP-8/L
2024-09-27 add ttpanel to display lamp and switch states continuously
    uses udp to inquire state from pipanel
2024-09-27 highlight active lights a little better with bold red
    also use pipanel 'setsw sr' for pdp8v switchregister
2024-09-27 updates to ttpanel
    default ttpanel ipaddress to 127.0.0.1
    update ttpanel to display frames-per-second
    change mprot -> mprt to be consistent everywhere
2024-09-29 add IOT opcode to assembler
    follow it with a number in range 06000..06777
2024-09-29 add looptest command to testmem.tcl and count errors
    looptest testzeroes
    loops the testzeroes case
    and breaks it into steps of 040 words
2024-09-30 rename pipanel to pipan8l and reference pdp8v github branch
    [pipan8l.kicad_pcb, pipan8l.kicad_sch]
2024-10-01 add note to readme.txt about pcb thickness
2024-10-01 add missing notitleblock.kicads_wks file and new simming.txt
2024-10-01 attempt to get zynq /dev/i2c-0 working
    ...gets occasional timeout errors
    [i2clib.cc]
2024-10-09 few small script changes
    - add steploop command to single step, dump, prompt for enter to step again
    - ignore EA bit when writing memory cuz there's no extended memory
    - turn off all switches on startup
    - can have testrands test use address bits in reverse to test upper address bits

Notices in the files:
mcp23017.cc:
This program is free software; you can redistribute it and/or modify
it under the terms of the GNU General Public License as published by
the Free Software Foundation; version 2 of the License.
